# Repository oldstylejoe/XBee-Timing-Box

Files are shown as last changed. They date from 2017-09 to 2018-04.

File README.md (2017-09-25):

# XBee Timing Box

## Goal.

The goal of this timing box is to have low latency, high reliability, and usability in a clinical setting. It must also have sub-millisecond variability in the latency of the pulses.

The XBee (IEEE 802.15.4) protocol fits the bill. It has low latency at about 10.0(1) ms and seems to be reliable in the clinical setting. XBee also has a thriving community, largely driven by its usage in RC drones. A breakout board from SparkFun (Fio V3) already takes care of most of the work. It is mounted on a board (or even a proto-board) and connected to a shift register to give a TTL-type timing pulse.

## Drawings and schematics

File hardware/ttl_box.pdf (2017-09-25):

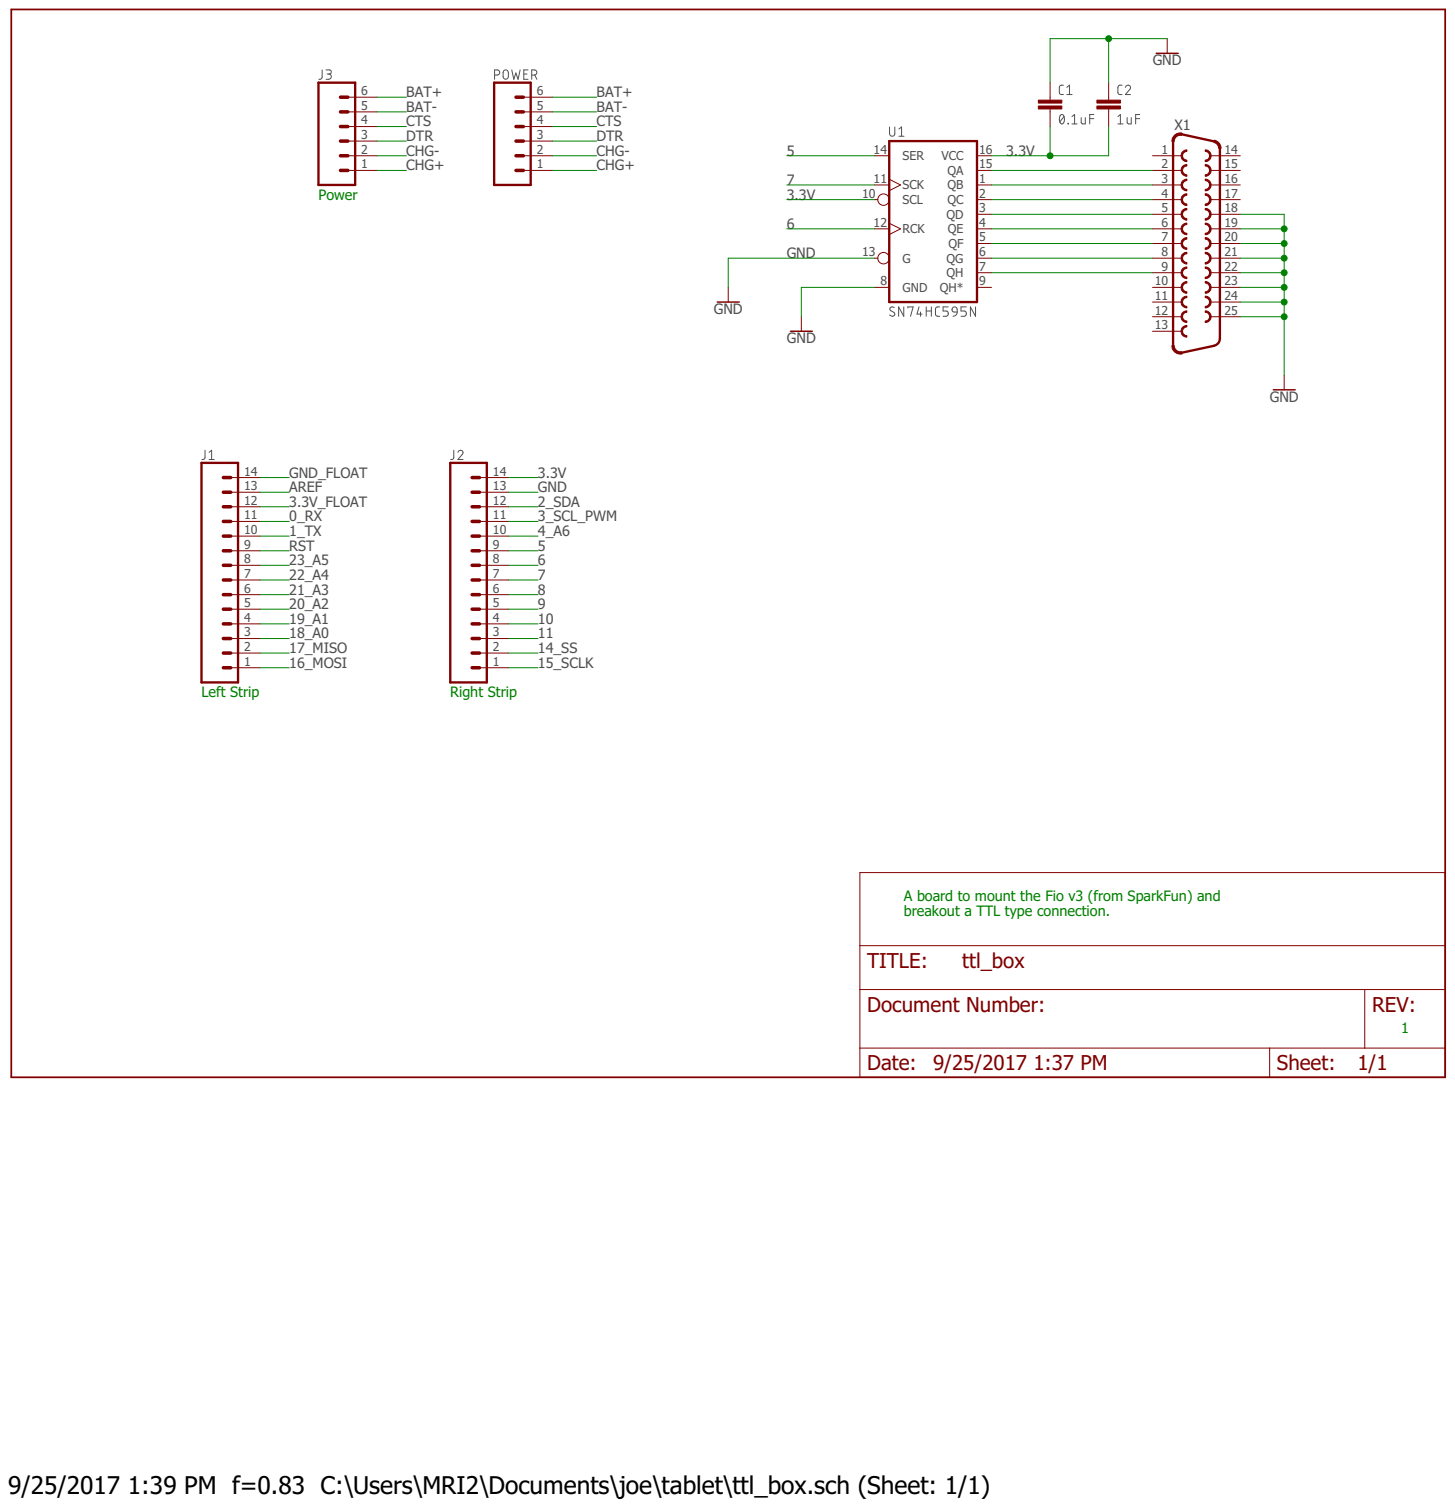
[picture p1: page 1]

A board to mount the Fio v3 (from SparkFun) and
breakout a TTL type connection.

Document Number: | REV: 1

Date: 9/25/2017 1:37 PM | Sheet: 1/1

9/25/2017 1:39 PM f=0.83 C:\Users\MRI2\Documents\joe\tablet\ttl_box.sch (Sheet: 1/1)

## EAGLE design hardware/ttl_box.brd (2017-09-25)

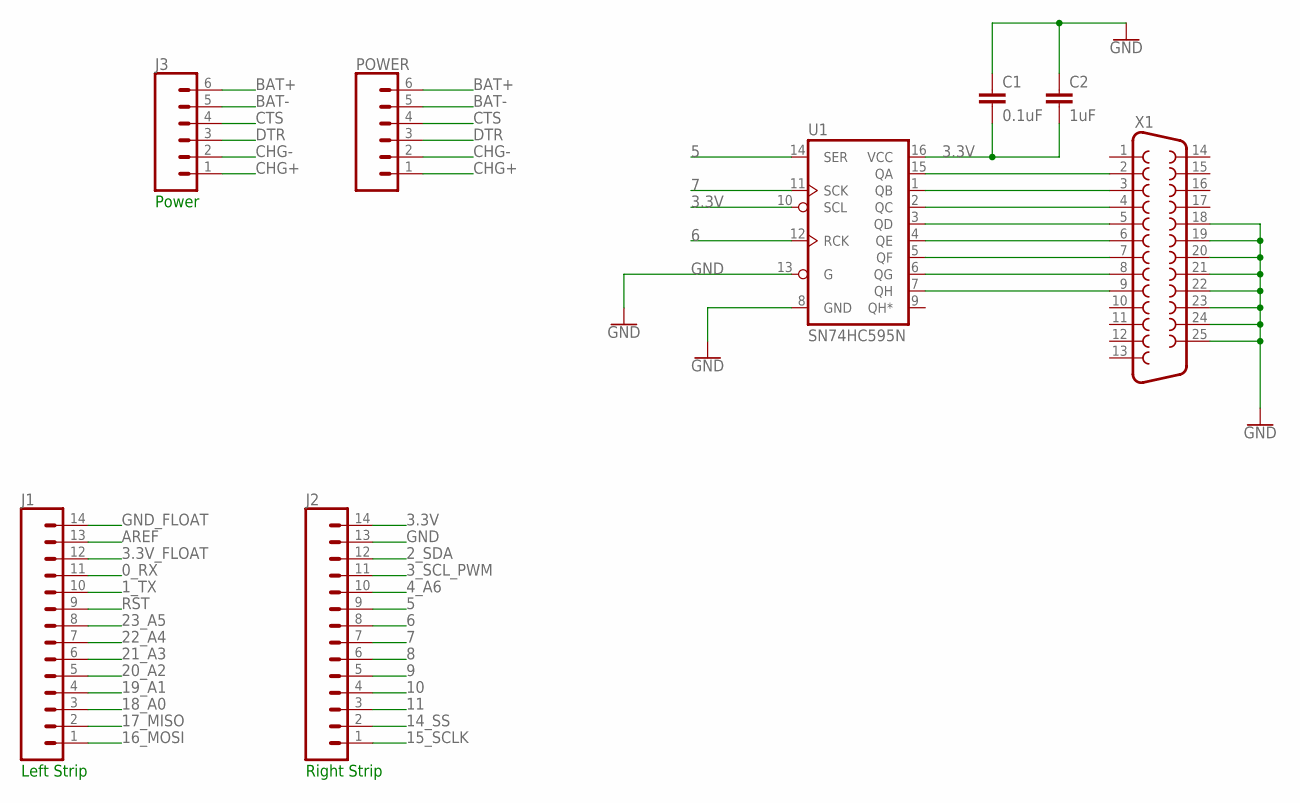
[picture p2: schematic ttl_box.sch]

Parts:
C1: 0.1uF; CAP-PTH-SMALL-KIT
C2: 1uF; CAP-PTH-SMALL-KIT
J1, J2: CONN_14; 1X14
J3: CONN_06SILK_FEMALE_PTH; 1X06
POWER: CONN_06SILK_FEMALE_PTH; 1X06
U1: SN74HC595N; DIP16
X1: DB25_FEMALEVB; F25VB

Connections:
0_RX: J1.11
1_TX: J1.10
2_SDA: J2.12
3.3V: C1.2, C2.2, J2.14, U1.10 (SCL), U1.16 (VCC)
3.3V_FLOAT: J1.12
3_SCL_PWM: J2.11
4_A6: J2.10
5: J2.9, U1.14 (SER)
6: J2.8, U1.12 (RCK)
7: J2.7, U1.11 (SCK)
8: J2.6
9: J2.5
10: J2.4
11: J2.3
14_SS: J2.2
15_SCLK: J2.1
16_MOSI: J1.1
17_MISO: J1.2
18_A0: J1.3
19_A1: J1.4
20_A2: J1.5
21_A3: J1.6
22_A4: J1.7
23_A5: J1.8
AREF: J1.13
BAT+: J3.6, POWER.6
BAT-: J3.5, POWER.5
CHG+: J3.1, POWER.1
CHG-: J3.2, POWER.2
CTS: J3.4, POWER.4
DTR: J3.3, POWER.3
GND: C1.1, C2.1, J2.13, U1.8 (GND), U1.13 (G), X1.18, X1.19, X1.20, X1.21, X1.22, X1.23, X1.24, X1.25
GND_FLOAT: J1.14
unnamed: U1.15 (QA), X1.2
unnamed: U1.1 (QB), X1.3
unnamed: U1.2 (QC), X1.4
unnamed: U1.3 (QD), X1.5
unnamed: U1.4 (QE), X1.6
unnamed: U1.5 (QF), X1.7
unnamed: U1.6 (QG), X1.8
unnamed: U1.7 (QH), X1.9
RST: J1.9

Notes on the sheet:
Power
Left Strip
Right Strip

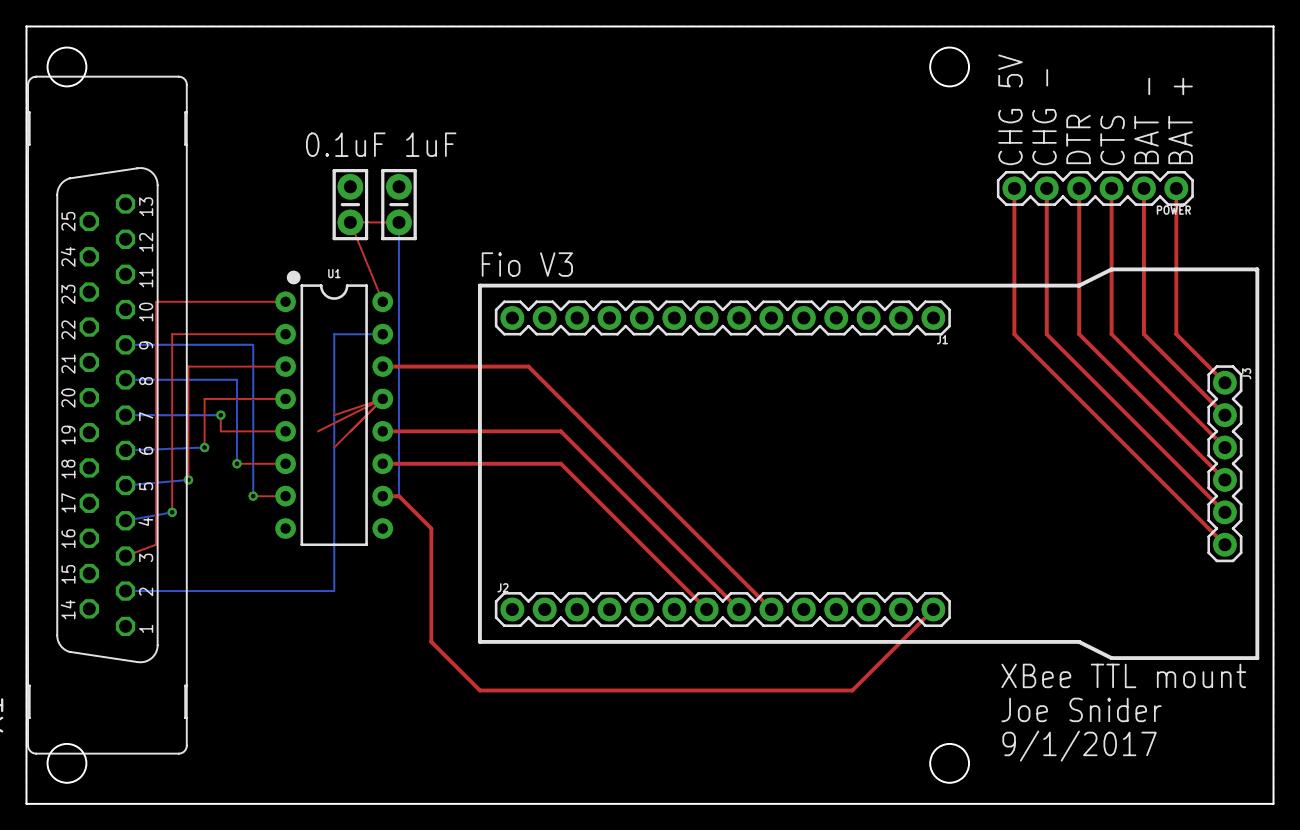
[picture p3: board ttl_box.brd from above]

Board: 2 copper layers, 97.8 x 61.0 mm, 8 parts (0 on the bottom side), 19 nets.

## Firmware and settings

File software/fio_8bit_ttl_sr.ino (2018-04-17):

//Joe Snider
//6/15
//
//receive ascii from a Serial connection and send pulses out on digital pins.
//
//10/15
//Now goes into a default mode of sending a double pulse of 20ms every 1-5 seconds
// (parameters set below, double check) if it hasn't heard from the 
// XBee for a given time (100s).
//Potential problem: If this is actively sending the default pulse, then the wake
// pulse might be confused.
//
//3/16 updated for NYU to have default pulses every 20-30 seconds.
//
//11/16 updated to use a shift register. This turns on all the pins at the same time.

unsigned long pulseTime = 100;//ms
bool inPulseMode = false;
unsigned long pulseOffTime;
bool reportNextPulse = false;

unsigned long deafultPulseTime = 20;//ms
unsigned long deadTime = 100000;//ms //time to wait without anything from XBee
unsigned long lastPulseTime;
unsigned long nextDefaultPulse;
unsigned long defaultDelay[] = {20000, 21000, 22000, 23000, 24000, 25000, 26000, 27000, 28000, 29000, 30000};//ms
unsigned long nDelays = 11;//number of entries in the array above
bool inDefaultMode;

unsigned long latencyCheck = 0;

int latchPin = 7;
int clockPin = 8;
int dataPin = 9;

void setup() {
  Serial.begin(9600);
  Serial1.begin(9600);
  pinMode(A0, INPUT);
  pinMode(latchPin, OUTPUT);
  pinMode(dataPin, OUTPUT);  
  pinMode(clockPin, OUTPUT);

  pinMode(13, OUTPUT);

  //start out in the default mode
  inDefaultMode = true;
  lastPulseTime = millis();
  randomSeed(analogRead(0));
  
  //while (!Serial);
  updateShiftRegister(0);
}

int inByte;

void loop() {
  if(Serial1.available() > 0 && !inPulseMode) {
    inByte = Serial1.read();

    updateShiftRegister(inByte);
    digitalWrite(13, HIGH);

    inDefaultMode = false;
    inPulseMode = true;

    lastPulseTime = millis();
    pulseOffTime = lastPulseTime + pulseTime;// may roll over

    //clear anything in serial
    while(Serial1.available() > 0) {
      Serial1.read();
    }
  }

  //turn off pulse, safe for roll-over
  if(inPulseMode && (long)(millis() - pulseOffTime) > 0) {
    updateShiftRegister(0);
    digitalWrite(13, LOW);
    inPulseMode = false;
  }
  
  //report the latency if we get a pulse on the standard serial port
  if(reportNextPulse && inPulseMode && analogRead(A0) > 255) {
    long latency = millis() - latencyCheck;
    reportNextPulse = false;
    Serial.print("latency: ");
    Serial.print(latency);
    Serial.println(" ms");
  }

  if(Serial.available()) {
    latencyCheck = millis(); //no worry about roll over, deal with it
    reportNextPulse = true;
    while(Serial.available() > 0) {
      Serial.read();
    }
  }

  //enter default mode after a delay, rollover safe
  if(!inDefaultMode && (long)(millis() - lastPulseTime - deadTime) > 0) {
    inDefaultMode = true;
    nextDefaultPulse = millis();
    updateShiftRegister(0);
    digitalWrite(13, LOW);
    inPulseMode = false;
  }

  if(inDefaultMode && (long)(millis() - nextDefaultPulse) > 0) {
    //this will block and delay the XBee trigger.
    //Have to add some sort of test to skip any allignment tags with a double tap within
    //  (about) 1us (10ms is probably reasonable, or just always skip the first one).

    digitalWrite(13, HIGH);
    updateShiftRegister(B11111111);
    delay(deafultPulseTime);
    updateShiftRegister(0);
    delay(deafultPulseTime);
    updateShiftRegister(B11111111);
    delay(deafultPulseTime);
    updateShiftRegister(0);
    digitalWrite(13, LOW);

    nextDefaultPulse = millis() + defaultDelay[random(nDelays)];
  }
}

//this sends whatever is stored in leds to the pins.
//It is big endian (I think, B00000001 fires pin 2 on the db25)
void updateShiftRegister(byte leds)
{
  byte mask = B10000000;
   digitalWrite(latchPin, LOW);
   for(int i = 0; i < 8; ++i) {
    digitalWrite(dataPin, LOW);
    if( (leds & mask) == mask) {
      digitalWrite(dataPin, HIGH);
    }
    digitalWrite(clockPin, HIGH);
    digitalWrite(clockPin, LOW);
    leds <<= 1;
   }
   //shiftOut(dataPin, clockPin, LSBFIRST, leds);
   digitalWrite(latchPin, HIGH);
}

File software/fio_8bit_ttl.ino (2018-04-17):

//Joe Snider
//6/15
//
//receive ascii from a Serial connection and send piulsed

float pulseTime = 100;//ms

void setup() {
  Serial.begin(9600);
  pinMode(2, OUTPUT);
  pinMode(3, OUTPUT);
  pinMode(4, OUTPUT);
  pinMode(5, OUTPUT);
  pinMode(6, OUTPUT);
  pinMode(7, OUTPUT);
  pinMode(8, OUTPUT);
  pinMode(9, OUTPUT);
  
  //put in a delay for the XBee to negotiate
//  delay(1000);
}

int inByte;

void loop() {
  if(Serial.available() > 0) {
    inByte = Serial.read();
    
    int mask = 1; //todo - make global array for constant time deref
    for(int b = 0; b < 8; ++b) {
      if(mask & inByte) {
        digitalWrite(b+2, HIGH);
        //Serial.print("pin ");
        //Serial.println(b);
      }
      mask = mask << 1;
    }
    delay(pulseTime);
    for(int b = 0; b < 8; ++b, mask <<= 1) {
      digitalWrite(b+2, LOW);
    }
    
    //clear anything in serial
    while(Serial.available() > 0) {
      Serial.read();
    }
    
  }
}

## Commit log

2017-09-25 first hardware
    [ttl_box.brd, ttl_box.sch]
2018-04-17 uploaded shift register arduino code

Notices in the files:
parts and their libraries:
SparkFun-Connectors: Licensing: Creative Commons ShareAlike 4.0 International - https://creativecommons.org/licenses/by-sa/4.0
